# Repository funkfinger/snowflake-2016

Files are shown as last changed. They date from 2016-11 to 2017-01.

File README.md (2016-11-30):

# snowflake-2016
An ATtiny based snowflake ornament. Happy Holidays friends...

### Board shape
  * created the board in Illustrator and added extra points (`Object -> Path -> Add Anchor Points`).
  * exported shape as `DXF` - settings:
    * R13/LT95
    * scale - 1mm = 1 unit
    * colors 256 - PNG
    * max editabitity
    * export selected art only
  * import shape using `import_dxf_polygons_v4.ulp` ([found here](https://raw.githubusercontent.com/todbot/eagle-tricks/master/import_dxf_polygons_v4.ulp)) - settings:
    * scale 1
    * import to layer: 20 - dimension
    * wire or polygon: wire
    * pen width: .2
  * make sure shape is 'watertight' - had to clean up small space on snowflake in Eagle by drawing a 'wire' to close.

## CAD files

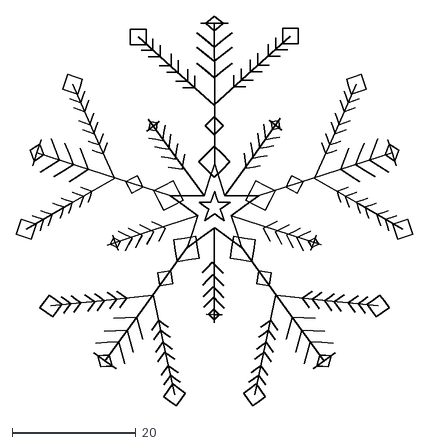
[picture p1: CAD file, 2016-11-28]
board/snowflake-image.dxf
64.1 x 63.0

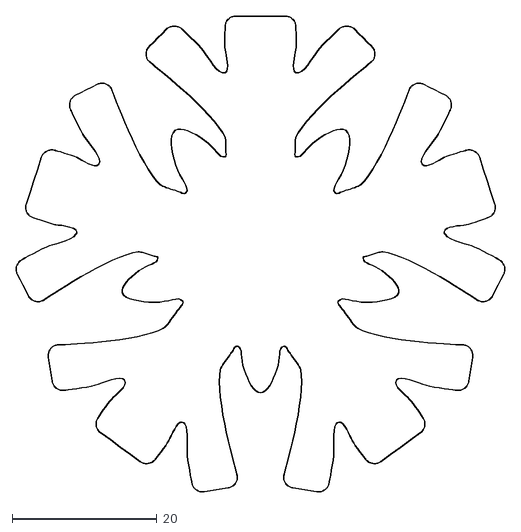
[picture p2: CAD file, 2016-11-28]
board/board-shape.dxf
67.5 x 65.8

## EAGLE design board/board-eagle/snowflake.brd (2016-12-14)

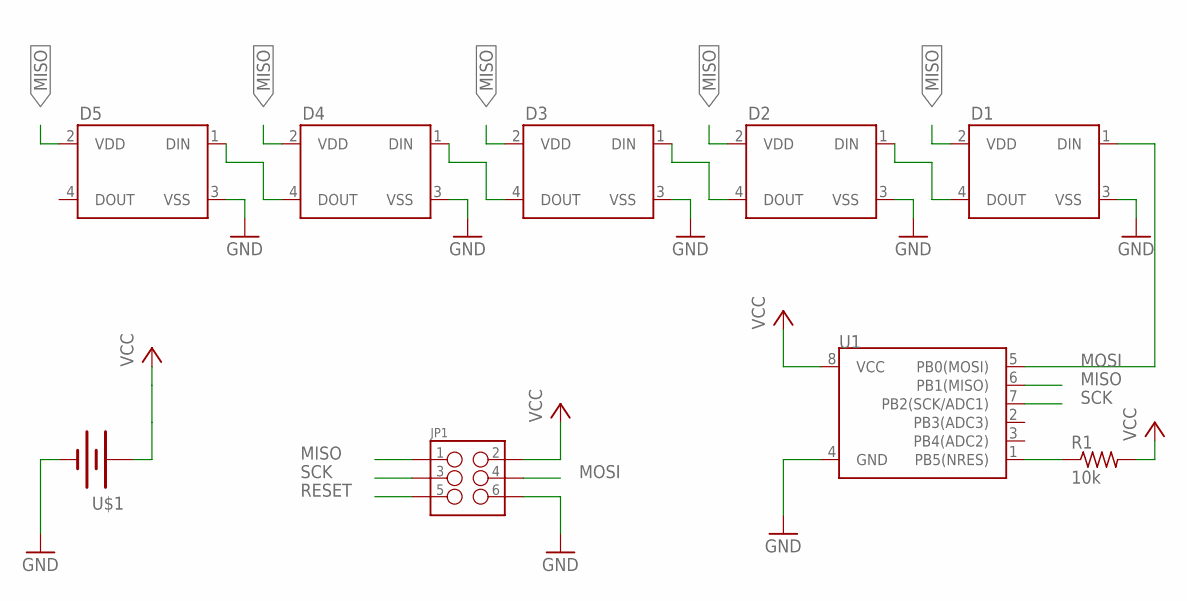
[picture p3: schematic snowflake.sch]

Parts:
D1, D2, D3, D4, D5: WS2812BEDGE_MOUNT_5MM_LED; WS2812B
JP1: M03X2POGO_PINS; 2X3_POGO
R1: 10k; R0805
U1: ATTINY45TINY85-20-SMT; SO08-EIAJ
U$1: BATTERY; BHX2-2032-SM

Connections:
GND: D1.3 (VSS), D2.3 (VSS), D3.3 (VSS), D4.3 (VSS), D5.3 (VSS), JP1.P$6 (6), U1.4 (GND), U$1.GND (-)
MISO: D1.2 (VDD), D2.2 (VDD), D3.2 (VDD), D4.2 (VDD), D5.2 (VDD), JP1.P$1 (1), U1.6 (PB1(MISO))
MOSI: D1.1 (DIN), JP1.P$4 (4), U1.5 (PB0(MOSI))
unnamed: D1.4 (DOUT), D2.1 (DIN)
unnamed: D2.4 (DOUT), D3.1 (DIN)
unnamed: D3.4 (DOUT), D4.1 (DIN)
unnamed: D4.4 (DOUT), D5.1 (DIN)
RESET: JP1.P$5 (5), R1.1, U1.1 (PB5(NRES))
SCK: JP1.P$3 (3), U1.7 (PB2(SCK/ADC1))
VCC: JP1.P$2 (2), R1.2, U1.8 (VCC), U$1.VCC (+), U$1.VCC-2 (+)

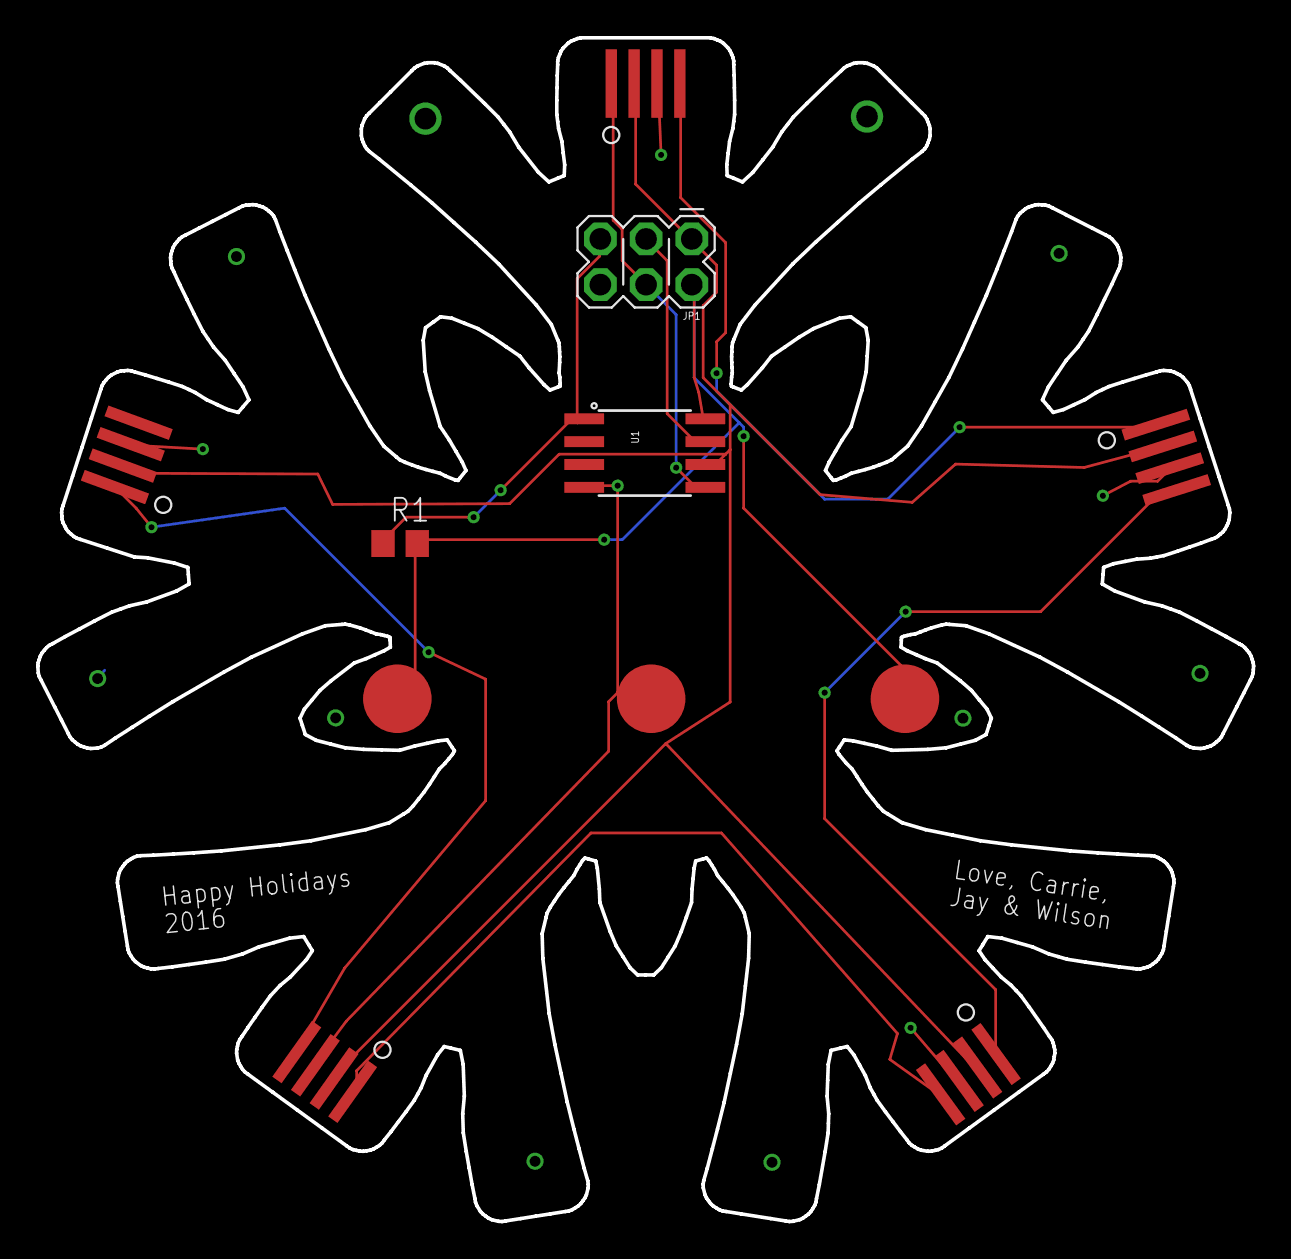
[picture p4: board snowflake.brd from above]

Board: 2 copper layers, 67.5 x 65.8 mm, 9 parts (0 on the bottom side), 10 nets.

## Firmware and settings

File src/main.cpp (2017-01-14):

// fuse settings...
// avrdude -c usbtiny -p attiny85 -U lfuse:w:0xe2:m -U hfuse:w:0xdf:m -U efuse:w:0xff:m

#include <FastLED.h>
#define NUM_LEDS 5
#define DATA_PIN 0

#include <avr/power.h>
#include <avr/sleep.h>

#define set(x) |= (1<<x)
#define clr(x) &=~(1<<x) 
#define inv(x) ^=(1<<x)

void nightyNight();
uint8_t awakeCounter = 110;

// CRGB leds[NUM_LEDS];
CRGBArray<NUM_LEDS> leds;
 
void setup() {
  // power control pin...
  DDRB set(DDB1);  
  
  // disable interrupts...
  cli();
  
  // reset the 'why the cpu was reset' flag...
  MCUSR = 0;

  // disable and clear watchdog settings a la ATtiny25/45/85 [DATASHEET] p. 46
	WDTCR = (1<<WDCE) | (1<<WDE);
	WDTCR = 0;
  
  //   // set interrupt time to about 1 second and enable...
  // WDTCR = (1<<WDIE) | (1<<WDP2) | (1<<WDP1);

  // set interrupt time to about 32ms and enable...
  WDTCR = (1<<WDIE) | (1<<WDP0);
  
  // enable sleep mode for power down...
  set_sleep_mode(SLEEP_MODE_PWR_DOWN);
  
  // enable interrupts...
  sei();
  
  // FastLED.addLeds<NEOPIXEL, DATA_PIN>(leds, NUM_LEDS);
  LEDS.addLeds<WS2812B,DATA_PIN, RGB>(leds, NUM_LEDS);
}

uint8_t ledsOn = 0;
void loop() {
  uint8_t color = 0;
  uint8_t currentPix = 0;
  uint8_t onTime = 0;
  
  uint8_t hue = 0;
  uint8_t hueDelta = 3;
  
  for (;;) {
    nightyNight();
    // digitalWrite(PORTB1, HIGH);
    // // Turn the first led red for 1 second
    // for(int dot = 0; dot < NUM_LEDS; dot++) {
    //    leds[dot] = CRGB::Red;
    //    FastLED.show();
    //    // clear this led for the next time around the loop
    //    leds[dot] = CRGB::Black;
    //    delay(30);
    // }

    // turn led pixels power on...

    if(awakeCounter == 0) {
      // turn off
      leds[0] = CRGB::Black;
      leds[1] = CRGB::Black;
      leds[2] = CRGB::Black;
      leds[3] = CRGB::Black;
      leds[4] = CRGB::Black;
      // WDTCR = (1<<WDIE) | (0<<WDP0);
      WDTCR = (1<<WDIE) | (1<<WDP0);
      FastLED.show();
      digitalWrite(PORTB1, LOW);      
    }

    if(awakeCounter > 200) {
      digitalWrite(PORTB1, HIGH);
      // WDTCR = (1<<WDIE) | (0<<WDP0);
      WDTCR = (1<<WDIE) | (1<<WDP0);
      onTime++;
      color++;
      if(currentPix == 4) {
        currentPix = 0;
      }
      else {
        currentPix++;
      }
      leds[0] = CRGB::Black;
      leds[1] = CRGB::Black;
      leds[2] = CRGB::Black;
      leds[3] = CRGB::Black;
      leds[4] = CRGB::Black;

      hue += hueDelta;
      // leds[currentPix] = CRGB::White;
      leds[currentPix].setHue(hue);
      FastLED.show();
    }
    else {
    }
  }
}


// reduce power requirements and go to sleep...
void nightyNight() {
  // disable adc...
  power_adc_disable();
  // go to sleep - sleep_cpu() requires more code to enable and disable sleep...
  sleep_mode();
}



ISR(WDT_vect) {
  awakeCounter++;
}

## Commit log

2016-11-26 adding board in illustrator
2016-11-26 update board in illustrator
2016-11-28 board design
    [board-shape.dxf, snowflake-image.dxf, snowflake.brd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]
2016-12-14 new board and zip
    [snowflake.brd, snowflake.sch]

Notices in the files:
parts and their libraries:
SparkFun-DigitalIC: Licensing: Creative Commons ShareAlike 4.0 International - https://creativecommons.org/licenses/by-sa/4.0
